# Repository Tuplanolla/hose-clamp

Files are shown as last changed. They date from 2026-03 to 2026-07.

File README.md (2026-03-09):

# Hose clamp

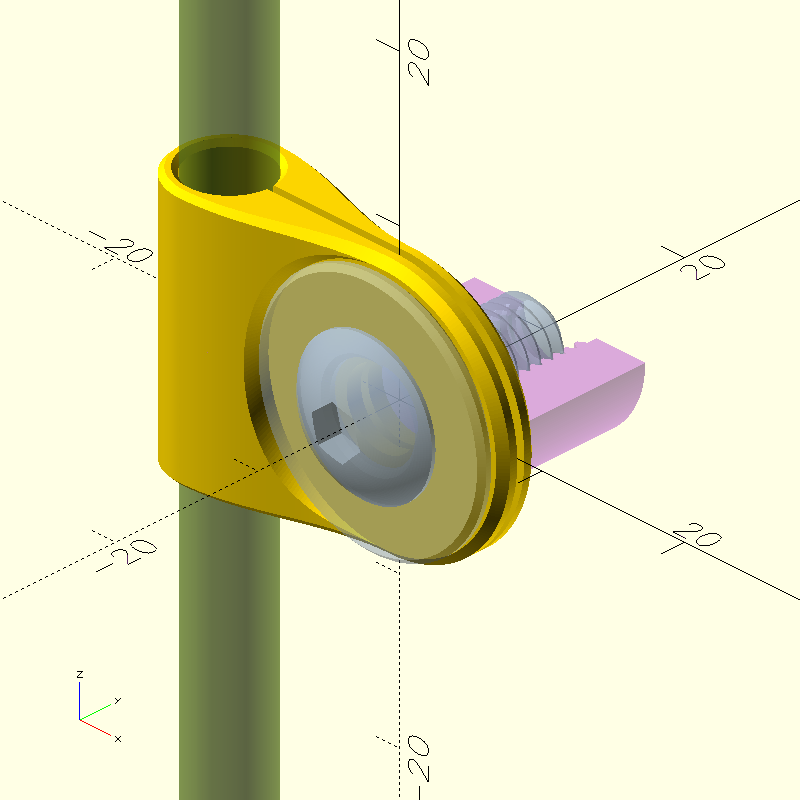
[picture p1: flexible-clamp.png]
Rendered image with default settings


This OpenSCAD program creates a clamp
for attaching a brake hose to the fork of a bicycle.
However, the program is much more flexible than that.
With minimal changes, it can also be used to create a clamp
for attaching a shifter cable housing to the frame of a bicycle,
attaching an audio cable to a synthesizer or
attaching a garden hose to the wall.
It also serves as a practical demonstration
of building fully constrained models with filleting and rounding.

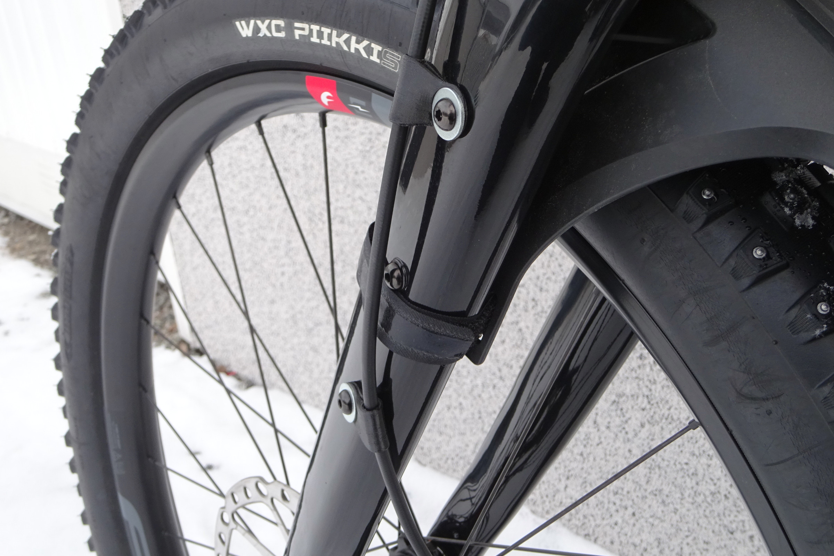
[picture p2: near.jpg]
Close-up photo of finished 3d prints


The default settings produce
a Tektro brake hose clamp for the Tandell PLUS29 Boost fork.
The fork in question has a channel down the left leg
for internal cable routing (at most 5 mm wide) and
three mounting bosses on each leg
for light cargo (at most 3 kg per side),
but has no other amenities for external cable routing or
mounting fenders, reflectors or lamps.
These clamps allow attaching a brake hose
to one or two of the bosses on the left leg,
so that swapping the fork does not require dismantling the brakes.

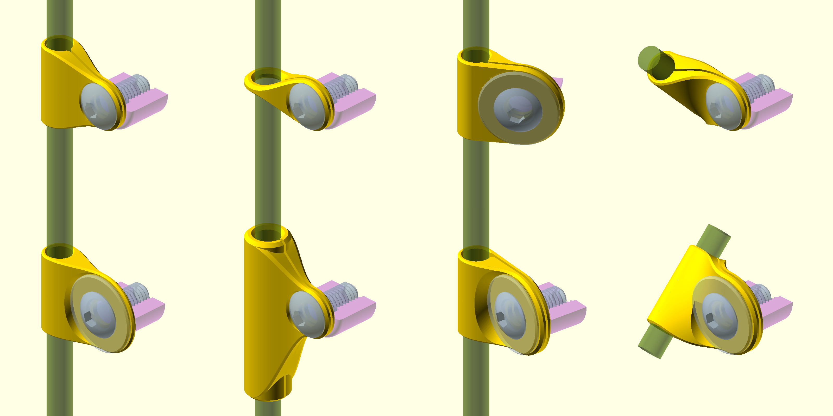
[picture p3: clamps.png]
Rendered montage with different settings


This project was created by Sampsa Kiiskinen on 2026-02-28 and
it is licensed under the GNU General Public License version 3 or later.
It is not intended to be developed any further,
but generalizations and derivative works are always welcome.
See the source code for details.

| File | Description
|:---|:---
| `README.md` | Overview of the project (this file)
| `LICENSE` | Copy of the project's license
| `clamp.scad` | Source code of the parametric model
| `flexible-clamp.png` | Rendered image with default settings
| `flexible-clamp.stl` | Generated mesh with default settings
| `far.jpg` | Photo of finished 3d prints
| `near.jpg` | Close-up photo of finished 3d prints
| `clamps.png` | Rendered montage with different settings

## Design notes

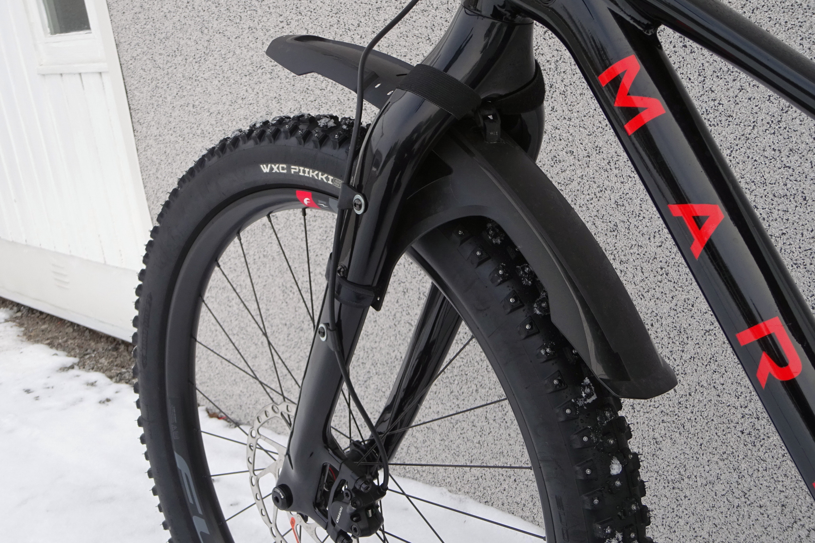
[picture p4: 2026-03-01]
far.jpg

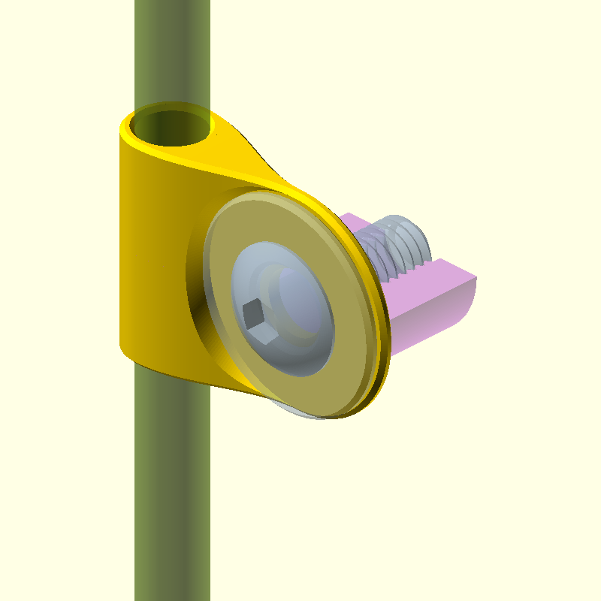
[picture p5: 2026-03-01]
uncut-clamp.png

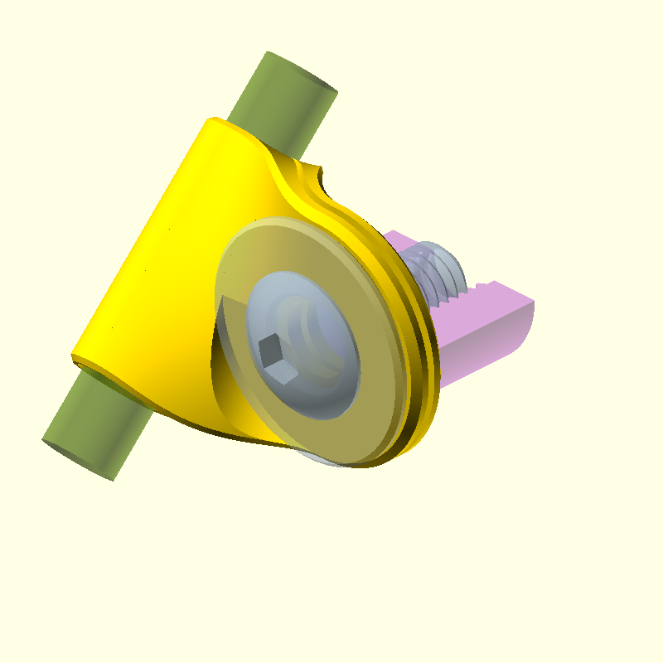
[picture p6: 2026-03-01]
loosened-clamp.png

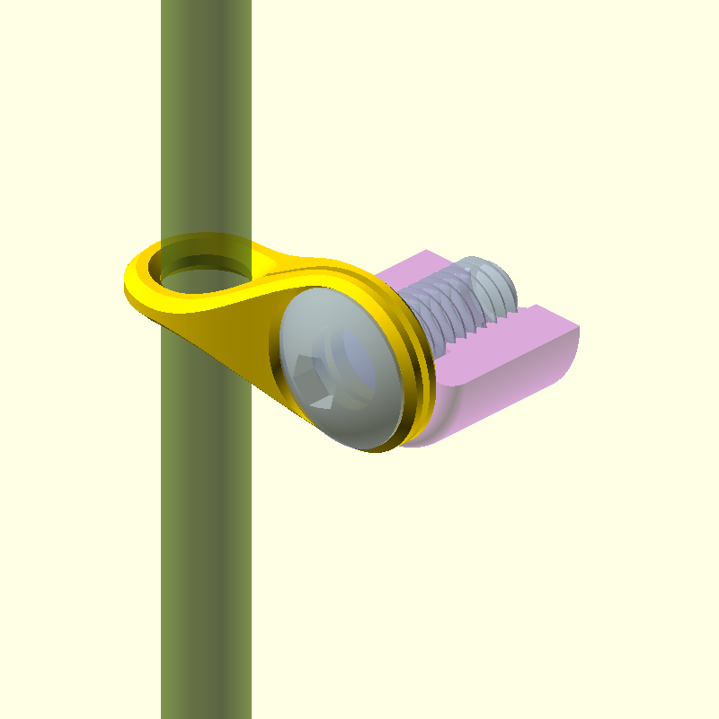
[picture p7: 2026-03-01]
short-clamp.png

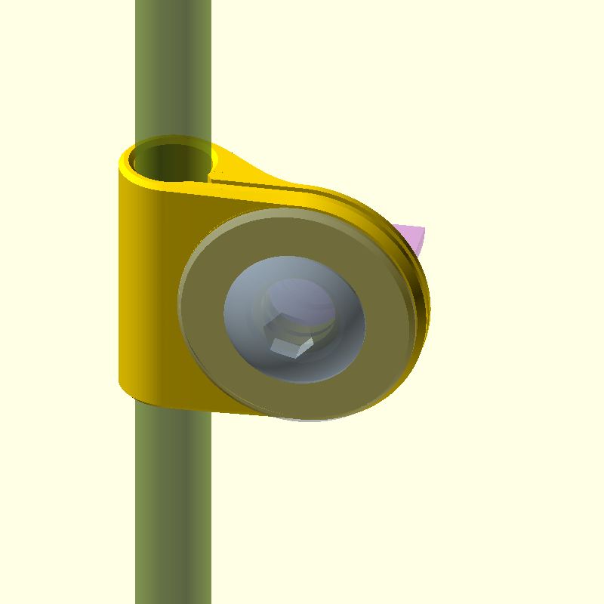
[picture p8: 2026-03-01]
convex-clamp.png

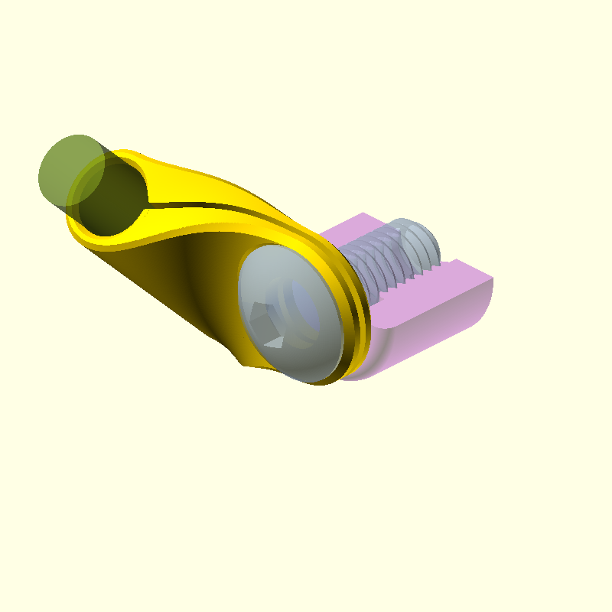
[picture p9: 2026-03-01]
tightened-clamp.png

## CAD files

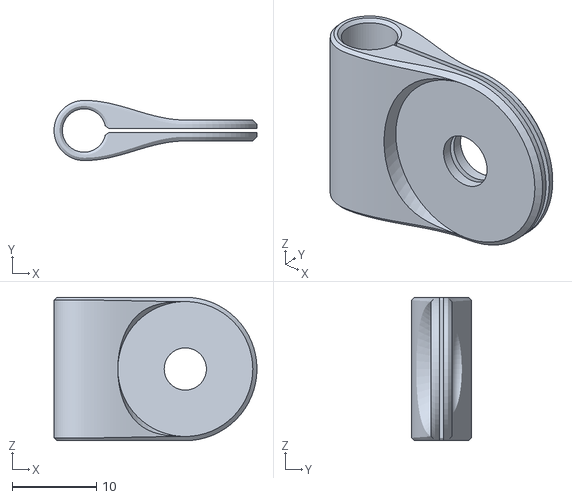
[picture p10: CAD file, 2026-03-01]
flexible-clamp.stl
24.1 x 7.13 x 17.0

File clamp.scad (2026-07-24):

include <BOSL2/std.scad>
include <BOSL2/screws.scad>
include <BOSL2/screw_drive.scad>

/// The following definitions are missing from the support libraries,
/// even though they are very convenient.

/// Linearly (or affinely) map the value `u` from `0` to `1`
/// to the value `v` from `a` to `b`.
// function lerp(a, b, u) =
// a + (b - a) * u;

/// Linearly (or affinely) map the value `v` from `c` to `d`
/// to the value `u` from `0` to `1`.
function lirp(c, d, v) =
(v - c) / (d - c);

/// Linearly (or affinely) remap the value `v` from `c` to `d`
/// to the value `u` from `a` to `b`.
function lrp(c, d, a, b, v) =
lerp(a, b, lirp(c, d, v));

/// Compute the radius (or diameter) `a`
/// of the inscribed circle of an `n`-sided regular polygon
/// from the radius (or diameter) `b` of its circumscribed circle.
/// The default value for `n` is derived
/// from the current `$fn`, `$fa` and `$fs`.
function incircle(b = 1, n = undef) =
let (n = is_def(n) ? n : segs(b))
b * cos(180 / n);

/// Compute the radius (or diameter) `b`
/// of the circumscribed circle of an `n`-sided regular polygon
/// from the radius (or diameter) `a` of its inscribed circle.
/// The default value for `n` is derived
/// from the current `$fn`, `$fa` and `$fs`.
function circumcircle(a = 1, n = undef) =
let (n = is_def(n) ? n : segs(a))
a / cos(180 / n);

/// The model follows shortly.

$draft = ! true;
$fn = 16;
$e = 1e-3;

/// Let us first establish some terminology.
/// The part is called a clamp and it is used
/// for attaching a hose to a boss with a bolt and
/// an optional washer that goes under the head of the bolt.
/// The clamp consists of a hollow guide for the hose and
/// a perforated pair of flaps for the bolt.
/// The guide and flaps are connected by a body,
/// which is split apart to form a small gap.

/// The dimensions of the hose, boss and bolt are out of our control.
hose_diameter = 5;
boss_inner_diameter = 10;
boss_outer_diameter = 12;
boss_counterbore_diameter = 6;
boss_counterbore_depth = 3;
boss_height = 1;
bolt_diameter = 5;
/// The length of the bolt is the length of its shaft,
/// which is fully threaded for no reason.
bolt_length = 12;
bolt_head_diameter = 9.5;
bolt_head_height = 2.5;
/// The size of the drive is the diameter of its inscribed circle,
/// which is also the size of the matching hex key.
/// These measured values are only used
/// to sanity check against standard drive sizes.
bolt_drive_size = 3;
bolt_drive_depth = 2;

/// Basic laws of physics still apply.
assert(hose_diameter > 0);
assert(boss_inner_diameter > 0 &&
       boss_inner_diameter <= boss_outer_diameter);
assert(boss_counterbore_diameter >= bolt_diameter);
assert(boss_counterbore_depth >= 0);
assert(boss_height >= 0);
assert(bolt_diameter > 0);
assert(bolt_length >= boss_counterbore_depth);
assert(bolt_head_diameter >= bolt_diameter);
assert(bolt_head_height >= 0);
assert(bolt_drive_size > 0 &&
       bolt_drive_size <= bolt_head_diameter);
/// The drive depth may exceed the bolt length,
/// in which case the bolt is hollow.
assert(bolt_drive_depth > 0 /* &&
       bolt_drive_depth <= bolt_head_height + bolt_length */);

/// The dimensions of the clamp can be adjusted freely.
guide_length = 17;
guide_thickness = 1;
flaps_thickness = 2;
/// The gap can be omitted,
/// in which case the flaps are fused together.
/// Without the gap, the clamp must be slid on
/// before attaching the hose or putting olives on it.
cut_gap = true;
gap_size = 0.5;
/// If we make the clamp out of a very flexible material,
/// we should add a washer under the head of the bolt,
/// because otherwise the bolt may slip through the hole.
use_washer = true;
washer_inner_diameter = 6;
washer_outer_diameter = 16;
washer_thickness = 1;
/// Edges of the holes can be trimmed to be in line with the body.
/// Untrimmed edges are smoother from the inside,
/// but also less streamlined from the outside.
/// This option only really makes sense
/// when the guide length exceeds the outer diameter of the flaps.
trim_edges = true;
/// These offsets determine the placement of the hose
/// in relation to the boss.
/// Their constraints are not defined until later.
offset_x = - 12;
offset_y = 0;
offset_z = 0;
cut_straight = true;
twist_x = 0;

assert(guide_length > 0);
assert(guide_thickness > 0);
assert(flaps_thickness > 0);
assert(gap_size > 0 &&
       gap_size <= hose_diameter);
assert(washer_inner_diameter > 0 &&
       washer_inner_diameter < washer_outer_diameter);
assert(washer_thickness > 0);
assert(abs(twist_x) <= 90);

/// These options only affect the rendering
/// of the hose, boss, bolt and washer.
render_attachments = true;
hose_extra_length = 20;
boss_depth = 10;

assert(boss_depth > 0);

/// These values for chamfers produce the least sharp corners,
/// but they can be changed to other values within reason.
guide_chamfer_size = guide_thickness / 3;
flap_chamfer_size = flaps_thickness / 4;

/// Reason is such.
assert(guide_chamfer_size >= 0 &&
       guide_chamfer_size <= guide_thickness / 2 &&
       guide_chamfer_size <= guide_length / 2);
assert(flap_chamfer_size >= 0 &&
       flap_chamfer_size <= flaps_thickness / 2);

/// We follow a color scheme that makes it easy
/// to distinguish different materials.
/// Carbon fiber composite with steel or brass inserts
/// is drawn with violet--purple hues.
composite = "MediumOrchid";
/// Aluminum or steel with protective plating or coating
/// is drawn with blue--gray hues.
metal = "LightSteelBlue";
/// Any material with synthetic rubber or plastic sheathing
/// is drawn with yellow--green--teal hues.
plastic = "OliveDrab";
/// Any other material is drawn with the default gold color.
anything = "Gold";

/// This is the diameter of the recess
/// for the bolt and the optional washer.
head_diameter = max(use_washer ? washer_outer_diameter : 0,
                    bolt_head_diameter) + 2 * flap_chamfer_size;
/// This is the diameter of the recess for the boss.
foot_diameter = boss_outer_diameter;
recess_diameter = max(head_diameter, foot_diameter);
/// Referring to the uncorrected gap size
/// from this point on would be a mistake.
cut_size = cut_gap ? gap_size : 0;
cut_angle = cut_straight ? 0 : twist_x;

/// Tightening the bolt reduces the circumference of the guide.
/// We have to correct the diameter of the guide
/// to prevent it from compressing the hose too much.
/// The clamp actually behaves like a folded elastic beam,
/// but we simplify its treatment by assuming
/// that it behaves like a pair of hinged rigid arms.
/// If the bolt crimps the gap around the recesses by this factor,
/// the lengths of the arms can be computed
/// from the surrounding geometry.
crimping = 1;
/// The crimping factor has a few distinct regimes.
///
/// * A crimping factor of zero means that
///   there is one hinge at the back of the guide.
///   The hinge makes the flaps meet at their farthest point.
/// * A crimping factor of one half means that there
///   is a hinge at the back of the guide and
///   another hinge in the middle of the flaps.
///   The hinges make the flaps meet in the middle.
/// * A crimping factor of one means that
///   there is a hinge at the back of the guide and
///   another hinge on the outer edge of the flaps.
///   The hinges make the flaps meet at their nearest point.
///
/// A crimping factor smaller than zero is allowed,
/// but results in maximal compression of the hose
/// as the factor approaches negative infinity.
/// A crimping factor larger than one is also allowed,
/// but diverges at some point due to
/// the guide no longer being able to compress the hose.
assert(crimping < (1 + (guide_thickness / 2 + hose_diameter / 2
                                            + abs(offset_x)) /
                       (recess_diameter / 2)) /
                  2);
/// Inspect these values upon installation to estimate the crimping.
short_arm = guide_thickness / 2 + hose_diameter;
long_arm = guide_thickness / 2 + hose_diameter / 2 + abs(offset_x)
           - (2 * crimping - 1) * recess_diameter / 2;
echo(short_arm = short_arm, long_arm = long_arm);
/// Referring to the uncorrected hose diameter
/// from this point on would be a mistake.
guide_inner_diameter = hose_diameter + (short_arm / long_arm) * cut_size / PI;
guide_outer_diameter = guide_inner_diameter + 2 * guide_thickness;

flaps_depth = flaps_thickness + cut_size;
/// This is the maximum depth of the recesses.
recess_depth = guide_outer_diameter / 2 - flaps_depth / 2 + abs(offset_y);
/// This is the maximum height of the clamp.
body_length = max(guide_length, guide_outer_diameter,
                  recess_diameter, flaps_depth);
/// Hollowing the guide and cutting the clamp benefit
/// from knowing the maximum dimensions of the clamp in any direction.
hollowing_depth = body_length + 2 * abs(offset_z)
                              + sin(abs(cut_angle)) * body_length;
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

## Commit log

2026-01-09 First print.
    [tandell-plus29-sharp.stl, tandell-plus29-smooth.stl, tandell-plus29.scad]
2026-02-16 Second print.
    [tandell-plus29-sharp.stl, tandell-plus29-smooth.stl, tandell-plus29.scad]
2026-02-20 Checkpoint before generalizing.
    [tandell-plus29.scad]
2026-03-01 Third and final print.
    [clamp.scad, flexible-clamp.stl]
2026-03-02 Clean up.
    [clamp.scad, tandell-plus29.scad]
2026-07-24 Fix strange syntax errors.
    [clamp.scad]
